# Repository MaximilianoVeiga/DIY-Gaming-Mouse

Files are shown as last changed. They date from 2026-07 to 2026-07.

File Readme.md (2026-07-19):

# DIY Gaming Mouse

Video about why and how I made this, and what the various iterations were like: https://www.youtube.com/watch?v=h-Cdl4Vq9H4

This repository contains the code, schematic, PCB layout, and 3d model for a completely DIY gaming mouse, all designed around a Pixart PMW3360 sensor.

The firmware for this mouse uses a special debouncing algorithm that completely eliminates chatter without adding ANY latency, and eliminates bounce better than commercial mice do. Random double-clicks be gone!

None of the companies that make gaming mouse sensors sell them to consumers, including Pixart, so the sensor needs to be salvaged (or bought from a scalper, or a small business that specializes in reselling them).

<table>
  <tr>
    <td>
      
    </td>
    <td>
      
    </td>
  </tr>
  <tr>
    <td>
      opened mouse
    </td>
    <td>
      assembled mouse
    </td>
  </tr>
</table>

(The shell has a top, too, but it's turned off in this picture so you can see the PCB.)

## Features

- True zero-latency button debouncing with no glitching
- Buttons that will not develop double-clicking problems after only a few months
- Low-latency motion tracking (no smoothing)
- Completely open source (Apache 2.0 license)
- Even the hardware is open source! (except the processor and sensor)
- Ultra light-weight shell and assembly (55g in total)
- Fingertip-grip shell shape
- Extra middle mouse button
- - the button that normally controls DPI on other mice is mapped to M3
- PCB exposes extra unused pins from the rp2040 as test pads for hardware/firmware modding fun; attach your own sensors! or LEDs! whatever you want!
- Full 1000hz tracking

### Runtime controls

- **DPI** (default 1200): hold LMB + RMB + DPI + M4 and scroll the wheel. Saved to flash ~2 seconds after the last change (mbed KVStore), so it survives reboot. Fallback default is `DPI_DEFAULT` in `3360_Mouse_pico.ino` (value is DPI/100).
- **Lift-off distance / LOD** (default 2 mm): hold LMB + RMB + DPI + M5 and scroll the wheel. Range is 2–3 mm; also persisted after the same ~2 s debounce.
- **Button remapping**: compile-time only. Edit the `BUTTON_MAP[]` table in `3360_Mouse_pico.ino`. By default M3 and the DPI button share middle-click (last press wins), M4 is back, M5 is forward.

### Sensor modes

- With a real `srom_3360_0x05.h`, the firmware uploads SROM and checks SROM ID + Observation (SROM running).
- Without a real SROM, the build still succeeds using `srom_dummy_blank.h` and runs in **degraded** mode (tracking enabled, but spinouts/teleports are possible).
- If SPI/product-ID checks fail repeatedly, the mouse enters **limp mode**: buttons and wheel keep working, motion is suppressed, and recovery is retried every few idle seconds.

### Building the firmware

Main mouse firmware uses **Arduino Mbed OS RP2040 Boards** (`arduino:mbed_rp2040`), not earlephilhower `arduino-pico`.

```bash
arduino-cli core update-index
arduino-cli core install arduino:mbed_rp2040@4.6.0
# Sketch folder name must match the .ino basename:
mkdir -p /tmp/3360_Mouse_pico
cp 3360_Mouse_pico.ino relmouse_16.h srom_dummy_blank.h /tmp/3360_Mouse_pico/
# optional: cp srom_3360_0x05.h /tmp/3360_Mouse_pico/
arduino-cli compile --fqbn arduino:mbed_rp2040:pico /tmp/3360_Mouse_pico
```

Or open `3360_Mouse_pico.ino` in Arduino IDE 2.x and select an **Arduino Mbed OS RP2040** Pico board. See [HARDWARE_VERIFY.md](HARDWARE_VERIFY.md) for post-flash checks.

The SROM capture tool under `bios/spi_recorder` requires the **arduino-pico** core instead:

```bash
arduino-cli config add board_manager.additional_urls https://github.com/earlephilhower/arduino-pico/releases/download/global/package_rp2040_index.json
arduino-cli core update-index
arduino-cli core install rp2040:rp2040
arduino-cli compile --fqbn rp2040:rp2040:rpipico bios/spi_recorder
```

CI compiles both sketches on every push (main firmware always uses the dummy SROM path; proprietary SROM headers stay gitignored).

### Lint / format

CI also runs `clang-format` and `cppcheck` on the firmware sources, and compiles with `--warnings all`.

Locally (requires `cppcheck` on `PATH`, and `clang-format` 22.x — e.g. `pip install clang-format==22.1.8`):

```bash
# Apply or check format (.ino treated as C++)
python3 scripts/clang_format_firmware.py
python3 scripts/clang_format_firmware.py --check

cppcheck --language=c++ --enable=warning,style,performance,portability --error-exitcode=1 \
  --suppress=missingIncludeSystem --suppress=unusedFunction \
  3360_Mouse_pico.ino relmouse_16.h bios/spi_recorder/spi_recorder.ino
```

SROM blob headers (`srom_dummy_blank.h`, `srom_3360_*.h`) are excluded from formatting.

### Hardware verification checklist

After flashing, confirm on a real mouse:

1. Boot serial shows product id `66` / inverse `189` (0x42 / 0xBD). With a real SROM, also check a non-zero SROM id and Observation with bit 6 set.
2. Change DPI with the DPI chord, wait ~2 seconds, unplug/replug: DPI should restore and print `settings: loaded ...`.
3. Change LOD with the LOD chord the same way; lift height tracking stop should change between 2 mm and 3 mm.
4. Buttons/wheel still work if the sensor is disconnected (limp mode); motion should stop without stuck clicks.
5. Fast motion + rapid clicks should not drop presses; USB fail/recover messages may appear only under host stress.

TODO:

- Runtime remapping / macros (compile-time map already exists)
- "fun" optional features like WMO-style diagonal jaggy removal or optional in-firmware acceleration, anti-smoothing (prediction), angle snapping, cinematic smoothing, etc

## Required skills

You need to be familiar with, or be able to learn quickly:

- 3d printing
- how to use a "slicer" (e.g. Cura) to convert stl models to gcode (what your 3d printer uses)
- repeatedly making test prints
- how to clean up 3d prints and remove support material from fragile prints
- basic firmware code debugging skills
- the ability to read embedded C/C++ code
- the Arduino IDE (I use 2.x, not 1.x)
- desoldering (with a hot air rework station)
- soldering (with a soldering iron)
- soldering bodge wires to existing pieces of hardware without creating solder bridges (for SROM extraction)
- comfort using a hot air rework station to soften and fix misshapen parts on 3d printed objects if they print improperly
- the ability to do all of the above without wasting tons of money or burning your home down
- familiarity with PCB printing companies and PCB assembly manufacturers (JLCPCB, PCBWay, etc)
- patience

If you cannot do all of the above, you should have someone else build this project for you, rather than building it for yourself. Or, at the very least, I can't give you support if you don't have the skills needed to make this; I'm just some random guy.

You also need:

- access to a 3d printer that you can repeatedly print test prints on until they come out right
- a hot air rework station with temperature and air flow rate control
- a soldering iron with temperature control
- hot glue device (for securing the USB cable, nothing else)
- various small tools like screwdrivers, tweezers, cleanup blades / deburring tools, etc. for various parts of the building process

## Instructions

### 3D printing the shell

This assumes you're using a filament printer. Resin printers might work too, but I have never used one.

I print with PLA filament.

Print each of the STL files in the "Case Model" directory in their natural (not default!) orientations. To repeat, some of the models have to be rotated; they're saved in the orientation they have in the mouse, not the orientation they need to have on the 3d printer's build plate.

You need to convert the stl files to gcode yourself and run various test prints because each 3d printer and filament has different requirements for layer thickness, support cutoff angle, printing speed, z seam alignment placement, etc.

Cura will complain about certain pieces (like the shell bottom) not being "water tight", but it's wrong; the watertightness check doesn't handle multiple overlapping solids properly. The models will still slice correctly and without glitches.

The thumb pieces must be rotated into the orientation where they do not need any supports. This means the small part of the thumb piece is facing up, and the long part of the switch clamp section is on the bottom.

The scroll wheel must be rotated so that the thick cylinder part is on the bottom and the thin pin part is on the top. It must be printed with supports; any type of support is fine. It should be printed at 100% speed or lower, not higher, until it gets to the pin, at which point you MUST reduce the printing speed as low as you can tolerate. On my printer, a Sovol SV06, I had to turn it down to 25% speed. If your printer doesn't allow you to change the speed mid-print, you have to print at the low speed for the entire print. This is important; you have to print it slowly, because otherwise, the pin will be misaligned with itself and the scroll wheel will be off-balance and hit the middle mouse button switch with different pressures depending on where it is in its spin cycle.

Print the scroll wheel brace as-is.

Print the shell bottom as-is. However, if you have a heated printbed or chamber, you need to wait for it to completely cool before removing it. If you remove the print while it's warm, the bottom will bend and the mouse won't sit flat. Even with mouse feet, the sensor will be at the wrong height if the bottom is bent.

Print the shell top with tree supports and a support cutoff angle between 60 and 70 degrees. Do not use "standard"/traditional/grid supports; they will be too difficult to remove, and you will probably damage the print trying to remove them. On my printer, a Sovol SV06, 67 degrees was just right. If you have poor print quality, you might need to reduce the cutoff angle down to something silly like 50 degrees. If you have to go below 50 degrees, get a better printer, or make sure you're using the right filament at the right temperature, etc.

Once the shell top is printed, you need to use a deburring tool (or other hard, sharp metal implement) to remove a small amount of material from a certain curved edge along the seam where it meets the shell bottom, on the right side of the shell (with the button pieces away from you and the "butt" part towards you). The shell will fit together without removing a small amount of material from this part of the shell top, but it'll be misaligned by around a quarter of a millimeter and the right click won't quite work right. This material has to be removed because it sags during printing, and it sags during printing because of how support bridging works; the 3d model itself is correct.

You should print each part one-by-one and check for errors each time.

The final result will be somewhat rough and rugged, but it's a functional mouse shell.

### SROM preparation

Note: The SROM is optional, but highly recommended because it contains sensor firmware bugfixes. The firmware builds without an SROM: if `srom_3360_0x05.h` is missing, it falls back to `srom_dummy_blank.h` and skips SROM upload (with a serial warning). Without a real SROM, your mouse might experience glitchy behavior like "spinout" or have generally poor tracking. For example, while writing this and testing the firmware without an SROM, I click-and-dragged a title bar on a window, and then the mouse cursor teleported 300~400 pixels to the right for no reason.

The SROM needs to be captured from an existing mouse because it's copyrighted. Give it the name `srom_3360_0x03.h`, `srom_3360_0x04.h`, or `srom_3360_0x05.h`, depending on what version it is. I poked around github and found other projects using the 3360 SROM, and this seems to be the way they decided to name their SROM header files, so I'm copying the filename from them.

Once you have the SROM, place `srom_3360_0x05.h` next to `3360_Mouse_pico.ino` (or adjust the `__has_include` path in that file for your version). The sketch will pick it up automatically.

The below is instructions on how to capture the SROM from a commercial mouse.

Capture the SROM from a commercial 3360 mouse with this code, and a standalone raspberry pi pico (not this mouse's custom PCB): https://gist.github.com/wareya/0dc3498bd80be93c47b6f79aa9164321

Note: the above SROM capturing code requires you to use the "arduino-pico" board type in the Arduino IDE. But the firmware in this repostory requires you to use the "mbed OS" rp2040 board type.

Use a breadboard to make a ripping setup equivalent to that depicted in the following image:

EspAlvz

And this post: https://github.com/wareya/DIY-Gaming-Mouse/issues/6#issuecomment-2340009477

Be very careful not to create any solder bridges between any of the pins on the 3360.

Reconnect the mouse so that it reboots and sends the SROM to the sensor again.

The output should be exactly 4094 bytes long, and the second byte should be 0x03, 0x04, or 0x05 (different versions).

Repeat the capturing process until you get the same SROM several times, just to make sure that it captured properly. To capture the SROM again, you need to reboot the mouse. This can be plugging it in to your computer again, or disconnecting and reconnecting its USB power wire, or any safe method you prefer.

The MD5 checksums of the versions of the SROM that I know about are:

```
0x03 - C64F2BDA742DD1623D6A5DC869FC5E60
0x04 - 0BCB410858FF21D091DDC497D19BC943
0x05 - 337254C54AD82C689D4B9A58D06A3CF6
```

If you have an SROM with a different version number, it might not work with this firmware. It might, but it also might not. I can't provide support for other SROM versions.

After capturing the SROM data, save it in a formatted .h file formatted as such:

```c

#define SROM_LENGTH (4094)

const uint8_t PROGMEM srom[SROM_LENGTH] =
{
0x01,
0x<version number>,
// ...
// etc
};
```

I cannot distribute the SROM in this repository, because it's copyrighted proprietary code.

Disclaimer: The above steps do not bypass any copy protection, no encryption is being broken, and copyright law is not being violated by making your own backup copy of the sensor's SROM and using it on your own device. This is fully legal in reasonable countries (like the US).

### PMW 3360 sensor salvage

The Pixart PMW3360 is not sold commercially to hobbyists or small repair shops; to get one, you have to either buy an expensive breakout board, buy it from scalpers on aliexpress (or similar), or salvage it from an existing commercial mouse. This project assumes that you're salvaging it from an existing commercial mouse, after capturing the SROM from that mouse.

You need a hot air rework station, NOT a soldering iron, to desolder and salvage the 3360 safely. If you try to use a soldering iron, even with desoldering wick and/or a desoldering pump, you are VERY likely to fail to salvage it, damaging the pins or sensor internals in the process. The 3360 is somewhat sensitive to high temperatures, so you can only heat it up for a fairly short amount of time, and desoldering the ground pin with a soldering iron will get the sensor hot enough that it might start to damage it.

The 3360 sensor's lens is usually directly mounted to the sensor by melting its clear mounting pins down onto the top of the sensor's IC package.

Take the commercial mouse's PCB, scrape off (don't break off) the top melted part of the lens's mounting posts. Then, being careful not to damage anything, remove the lens from the sensor and PCB and put it somewhere safe.

Now, put the commercial mouse's PCB upside down on a non-flammable surface, in a workspace free of any flammable material. I cannot be held responsible if you start a fire in an unsafe workspace. You have been warned!

Before continuing, you might want to cover the bottom of the sensor with paper and/or tape to prevent anything from getting inside of it. If you do this, do it in a way that doesn't create a fire hazard.

Find the bottom of the sensor's pins. To each of these pins, apply a small amount of either leaded solder (if it's all you have) or low-temperature non-leaded solder paste/gel/etc (preferred) (NOT the same thing as flux!). You want to mix your solder into the existing solder on the pins because this will lower the melting temperature of the existing solder and make it easier to desolder the chip. Use a soldering iron or hot air tool at around 600F/300C to make the two types of solder mix together. Do not physically touch the PCB or pins with the hot air tool; rely only on the air itself.

Once the solder for each pin is mixed together, pass the hot air tool over each section of pins in a circular motion until the sensor eventually, finally comes loose. At this point, use any metal tool (like metal tweezers or a screw driver) to make sure the sensor fully comes out of the PCB.

Now, use a soldering iron to clean any excess remaining solder off of the pins. If the soldering iron ends up with too much solder on it, clean it off with brass/bronze wool or similar. Be warned that, at very high temperatures, brass wool is flammable. Do not use steel wool as a subtitute, as it is even more flammable.

### PCB building and assembly

Build gerber files and drill files and all the other necessary files (BOM, pick and place, etc) that your PCB manufacturer needs to print **and assemble** the PCB. Some of the components on the PCB are very, very delicate, so unless you're a genuine expert, trying to hand-solder them is doomed.

The plugin I use to manage JLCPCB part mappings is https://github.com/Bouni/kicad-jlcpcb-tools - this is the plugin that uses the `project.db` file. However, this file is just an sqlite database, so if you want to make sure you use the right parts with another manufacturer, you can open it up with any sqlite database viewer and get the LCSC part numbers and look them up individually, then find the equivalent part for your PCBA manufacturer. However, the PCB isn't designed to require you to do this; you can look up the parts individually instead (based on their values).

Once you have your PCBs, you need the following parts to manually solder to the board:

- 6 Omron D2F-01F switches (or compatible, e.g. D2FC)
- 11mm Alps-compatible scroll wheel encoder
- salvaged PMW 3360 sensor, undamaged, pins not bent
- - 3360 sensor's lens, with mounting posts still intact
- Four dupont-compatible header pins for connecting to USB cable (optional)
- spare discrete resistors in case you messed up any of the resistor values when ordering the PCB like I did

And the following additional parts for assembly:

- USB cable, ideally with dupont-compatible connectors (you can crimp them on yourself, you don't have to buy a special cable for this)
- 3d printed shell (2 parts)
- 3d printed side buttons (2 parts)
- 3d printed scroll wheel brace (1 part)
- 3d printed scroll wheel OR salvaged scroll wheel for 11mm Alps-compatible scroll wheel encoder with the right middle-mouse-button shaft thickness
- mouse feet (salvaged or custom) with approximately 0.6mm thickness (that's zero-point-six millimeters)

The mouse feet thickness is very important, within a quarter of a millimeter! Using any other thickness of mouse feet is likely to result in poor, glitchy tracking. The PMW3360 is VERY sensitive to VERY small changes in tracking distance.

Make sure you have screws the right size to screw everything together. I recommend doing a test-fit of the shell and plain PCB with screws before doing anything else. Be careful not to overtighten the side screws; doing so can cause their mounting holes to split. The PCB is held down with two screws and the case is held together with three screws. I used salvaged screws with a major diameter (outside edge of threads) of 2mm and a minor diameter of around 1.65~1.7mm, and the holes on the case were designed around these screws, but slightly different screws will still work.

PPRKHyR

Solder the dupont-compatible header pins to the PCB, or if you have a different plan to connect the PCB to USB, do that instead. Then, connect it to your computer and make sure you can program it with the Arduino IDE. If it doesn't work, try a different copy of the PCB. Don't continue until you know that the PCB and its rp2040 processor are working properly. You should also do a test-fit of the PCB inside the 3d printed shell bottom to make sure nothing went wrong in 3d printing, and that the edge cuts and drill holes on the PCB are accurate to how they were specified in the design files.

Solder each Omron switch to the board with the plungers aligned with the outline on the silkscreen illustration. Check and double check that the switches are fully flush with the board before and while you solder them; double check that they're flush after soldering the first pin.

Test fit the PCB into the shell bottom, and without screwing anything into anything else, attach the top half of the shell and make sure that the buttons can be clicked properly and aren't clicked just by attaching the top half of the shell. If they're hard to click or they click themselves, your 3d printer has poor tolerances, and you may need to adjust the button pieces by softening them with the hot air tool and bending them slightly until they fit just right. Once you're done here, remove the PCB from the shell.

Solder the scroll wheel encoder in into the RotaryEncoder footprint on the PCB. Be very sure that it's all the way down before and while soldering it. You may need to twist the pins very slightly with a pair of needle-nose pliers to get them to fit into their holes; the holes are very narrow, on purpose, to reduce the chance of solder bridges forming between them.

firefox_2024-04-07_00-51-23

(Example photo of a 11mm Alps-compatible encoder. 11mm is the distance between the center of the rotor and the surface of the PCB, not the top to bottom of the entire encoder.)

Solder the PMW3360 sensor to the center of the PCB, making VERY, VERY sure that it's in ALL THE WAY before and while soldering it. If it's not in all the way, the PCB may not fit properly in the shell, and/or the sensor may fail to track properly. The sensor must be mounted "upside-down" relative to the rest of the board, such that the text on it is upside-down compared to the text at the top of the board. If you put the sensor in the wrong way, it will look uncentered; if you put it in the right way (upside-down), it will look centered. If you get the wrong, the sensor might fry itself when you turn the mouse on, and the lens might not even fit against the sensor through the PCB.

Attach the lens to the sensor on the underside of the PCB. Then, slot the PCB into the bottom shell and make sure it fully fits all the way down.

If, at this point, you connect the mouse to USB again and check what it says in the Arduino IDE's "Serial Logger" when the mouse boots, and the SROM's ID is a value other than zero or 0xFF, the sensor is working properly. If it's working properly but still doesn't track, double check the value of the LED resistor; that's the component closest to the "U10" silkscreen text, also near four diodes arranged in a rectangle (not in a row). The resistor value should be 39 ohms, or something very close like 40. If the resistor value is wrong, you have to desolder it and bodge on 40 ohms worth of discrete resistors (I personally use two 20 ohm resistors in series). WARNING: Using too few ohms will permanently damage the sensor's LED and make the sensor useless.

Remove the PCB and fit the side button thumb pieces to their switches. This is difficult and should feel like you're almost going to break the thumb pieces, but not like you're definitely going to break them. The long piece of the switch brace should wrap around the "inside" of the switches (towards the other side button switch), not the "outside". To get the thumb pieces around the switches, first fit the "hook" to the bottom around the edge of the PCB, slightly offset from the switch, and rotate the thumb piece down so that the far end of its brace hits the top of the switch. Move it as far from the switch as you comfortably can, so that it doesn't have to bend too much to slide down past the top and around the other side of the switch. Once that happens, slide it towards the switch so that the small hook piece at the end of the brace fully wraps around the other corner of the switch. Repeat this for the other switch's thumb piece.

firefox_2024-04-08_01-20-12 firefox_2024-04-08_01-20-14 firefox_2024-04-08_01-20-17 firefox_2024-04-08_01-20-19

Above is a visual image series depicting the process for mounting the thumb button pieces. It's OK if they crack or break while attempting to fit them; they will still fit and work, just be slightly less snug than they're supposed to be.

Fit scroll wheel brace around the middle mouse button (near the right mouse button), with the spikes towards the "inside" of the mouse and away from the middle mouse button. Now fit the scroll wheel and make sure it's snug and properly balanced. If it's not, you'll need to reprint it.

Put the PCB back into the shell bottom and make sure it's still snug. Route the USB cable behind the support post in the back of the case (it has a screw hole in it) and around the right side of the PCB (NOT the left side), hugging the right side of the right mouse button, and then feed it out through the slot in the front. Use hot glue to secure the USB cable to that front slot. Make sure that it points relatively straight out the front when you hot glue it down.

Plug it in, compile and upload the firmware from the Arduino IDE, and make sure everything works. If it does, you're done! Just re-screw everything together. Be careful not to overtighten the side screws; doing so can cause their mounting holes to split.

## License

3360_Mouse_pico.ino, the main file of this project, is released under the Apache License, version 2.0.

relmouse_16.h is based on files from mbed OS, also licensed under the Apache License, version 2.0. https://github.com/arduino/ArduinoCore-mbed

The hardware design files (under "Case Model" and "KiCad schematic + PCB") are licensed under the SolderpadLicense, version 2.1, as follows:

```
Copyright 2024 wareya
SPDX-License-Identifier: Apache-2.0 WITH SHL-2.1

Licensed under the Solderpad Hardware License v 2.1 (the “License”); you may not use this file except in compliance with the License, or, at your option, the Apache License version 2.0. You may obtain a copy of the License at

https://solderpad.org/licenses/SHL-2.1/

Unless required by applicable law or agreed to in writing, any work distributed under the License is distributed on an “AS IS” BASIS, WITHOUT WARRANTIES OR CONDITIONS OF ANY KIND, either express or implied. See the License for the specific language governing permissions and limitations under the License.
```

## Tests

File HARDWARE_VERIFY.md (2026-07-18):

# Hardware verification

Use this checklist after flashing improved firmware. CI only proves compilation with the dummy SROM path.

## Boot / sensor

- [ ] Serial shows `product id: 66 (inverse: 189)` (0x42 / 0xBD)
- [ ] With real SROM: non-zero `srom id` and `observation` with bit 6 set (`ok`)
- [ ] Without real SROM: degraded-mode warning, buttons/wheel/motion still function

## Settings persistence

- [ ] DPI chord (LMB+RMB+DPI+M4 + wheel) changes DPI; after ~2 s serial prints `settings: saved`
- [ ] Power cycle restores DPI (`settings: loaded`)
- [ ] LOD chord (LMB+RMB+DPI+M5 + wheel) changes 2–3 mm and persists the same way
- [ ] Corrupt/missing KV record falls back to 1200 DPI / 2 mm LOD

## USB / input

- [ ] Rapid motion + clicks do not leave buttons stuck
- [ ] Under host stress, occasional `usb: recovered` is acceptable; cursor should not jump wildly after recover
- [ ] Wheel does not skip at moderate scroll speeds (~1 kHz report path)

## Limp / recovery

- [ ] Disconnecting sensor SPI (or bad wiring) enters limp mode: motion stops, buttons/wheel still work
- [ ] After reconnect and a few idle seconds, recovery attempt restores motion when IDs validate

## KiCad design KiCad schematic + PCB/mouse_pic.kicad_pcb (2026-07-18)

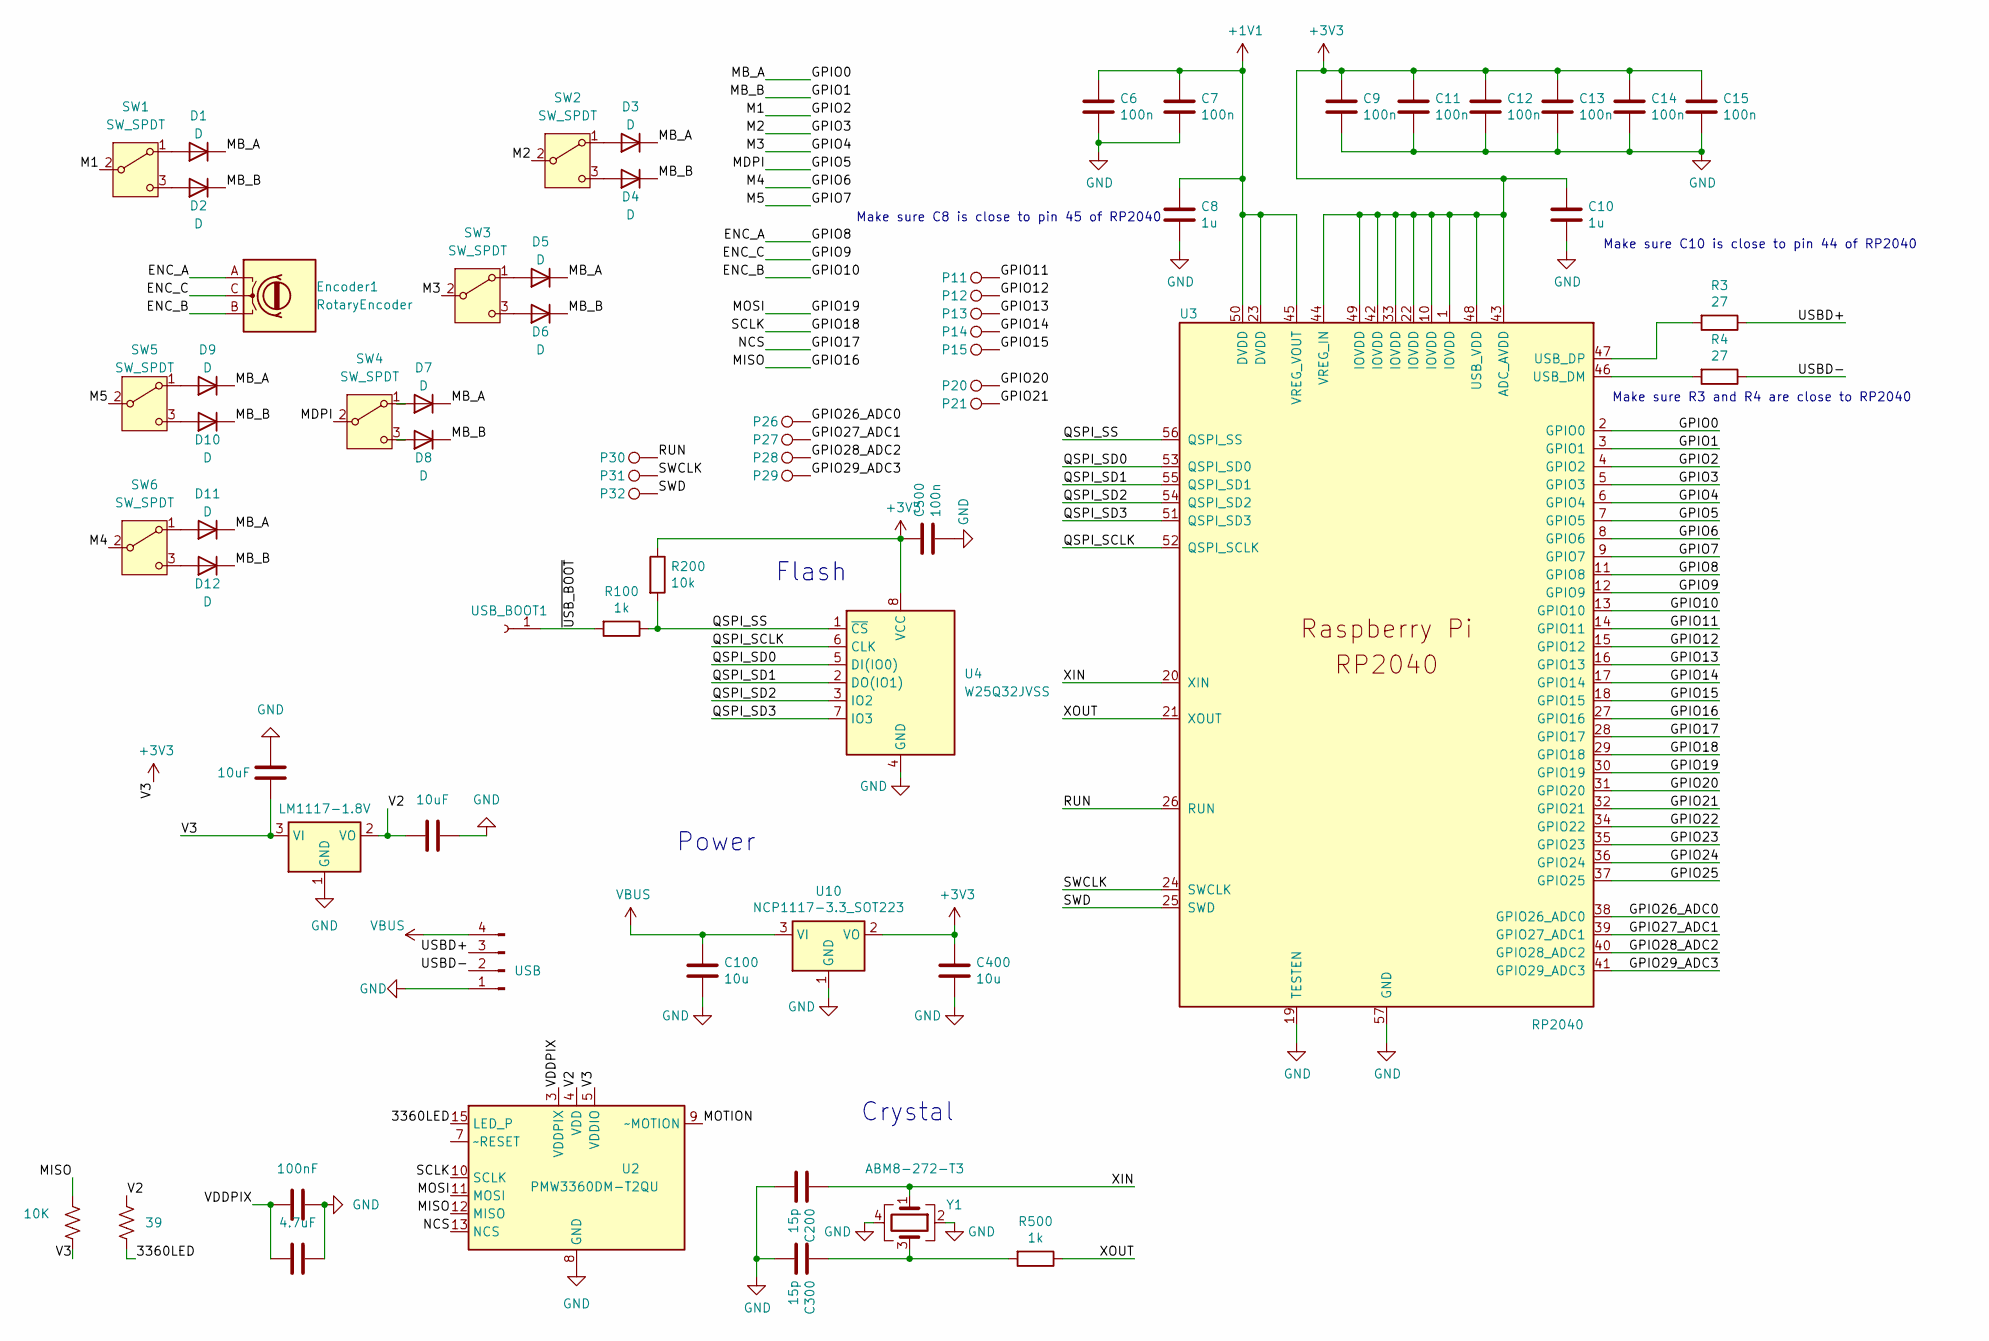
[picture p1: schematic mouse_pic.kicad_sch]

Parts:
C1, C2: 10uF; C_0603_1608Metric
C3: 100nF; C_0603_1608Metric
C4: 4.7uF; C_0603_1608Metric
C6, C7, C9, C11, C12, C13, C14, C15, C500: 100n; C_0603_1608Metric
C8, C10: 1u; C_0603_1608Metric
C100, C400: 10u; C_0603_1608Metric
C200, C300: 15p; C_0603_1608Metric
D1, D2, D3, D4, D5, D6, D7, D8, D9, D10, D11, D12: D; D_SOD-123
Encoder1: RotaryEncoder; Alps-EC10E1220501
P11, P12, P13, P14, P15, P20, P21, P26, P27, P28, P29, P30, P31, P32: TestPoint; TestPoint_Pad_D1.0mm
R1: 10K; R_0603_1608Metric
R3, R4: 27; R_0603_1608Metric
R40: 39; R_0603_1608Metric
R100, R500: 1k; R_0603_1608Metric
R200: 10k; R_0603_1608Metric
SW1, SW2, SW3, SW4, SW5, SW6: SW_SPDT; SW_Tactile_SPDT_Omron_D2F
U1: LM1117-1.8V; SOT-223-3_TabPin2
U2: PMW3360DM-T2QU; PixArt_PDIP-16_10.9x16.2mm_P1.78mm
U3: RP2040; RP2040-QFN-56
U4: W25Q32JVSS; SOIC-8_5.275x5.275mm_P1.27mm
U10: NCP1117-3.3_SOT223; SOT-223-3_TabPin2
USB1: USB; PinHeader_1x04_P2.54mm_Vertical
USB_BOOT1: Conn_01x01_Socket; TestPoint_THTPad_D2.0mm_Drill1.0mm_Edit
Y1: ABM8-272-T3; Crystal_SMD_3225-4Pin_3.2x2.5mm

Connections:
+1V1: C6.1, C7.1, C8.1, U3.23 (DVDD), U3.45 (VREG_VOUT), U3.50 (DVDD)
+3V3: C1.1, C9.1, C10.1, C11.1, C12.1, C13.1, C14.1, C15.1, C400.1, C500.1, R1.2, R200.1, U1.3 (VI), U2.5 (VDDIO), U3.1 (IOVDD), U3.10 (IOVDD), U3.22 (IOVDD), U3.33 (IOVDD), U3.42 (IOVDD), U3.43 (ADC_AVDD), U3.44 (VREG_IN), U3.48 (USB_VDD), U3.49 (IOVDD), U4.8 (VCC), U10.2 (VO)
/3360LED: R40.1, U2.15 (LED_P)
/ENC_A: Encoder1.A, U3.11 (GPIO8)
/ENC_B: Encoder1.B, U3.13 (GPIO10)
/ENC_C: Encoder1.C, U3.12 (GPIO9)
/GPIO0: D1.1 (K), D3.1 (K), D5.1 (K), D7.1 (K), D9.1 (K), D11.1 (K), U3.2 (GPIO0)
/GPIO1: D2.1 (K), D4.1 (K), D6.1 (K), D8.1 (K), D10.1 (K), D12.1 (K), U3.3 (GPIO1)
/GPIO2: SW1.2 (B), U3.4 (GPIO2)
/GPIO3: SW2.2 (B), U3.5 (GPIO3)
/GPIO4: SW3.2 (B), U3.6 (GPIO4)
/GPIO5: SW4.2 (B), U3.7 (GPIO5)
/GPIO6: SW6.2 (B), U3.8 (GPIO6)
/GPIO7: SW5.2 (B), U3.9 (GPIO7)
/GPIO11: P11.1, U3.14 (GPIO11)
/GPIO12: P12.1, U3.15 (GPIO12)
/GPIO13: P13.1, U3.16 (GPIO13)
/GPIO14: P14.1, U3.17 (GPIO14)
/GPIO15: P15.1, U3.18 (GPIO15)
/GPIO16: R1.1, U2.12 (MISO), U3.27 (GPIO16)
/GPIO17: U2.13 (NCS), U3.28 (GPIO17)
/GPIO18: U2.10 (SCLK), U3.29 (GPIO18)
/GPIO19: U2.11 (MOSI), U3.30 (GPIO19)
/GPIO20: P20.1, U3.31 (GPIO20)
/GPIO21: P21.1, U3.32 (GPIO21)
/GPIO22: U3.34 (GPIO22)
/GPIO23: U3.35 (GPIO23)
/GPIO24: U3.36 (GPIO24)
/GPIO25: U3.37 (GPIO25)
/GPIO26_ADC0: P26.1, U3.38 (GPIO26_ADC0)
/GPIO27_ADC1: P27.1, U3.39 (GPIO27_ADC1)
/GPIO28_ADC2: P28.1, U3.40 (GPIO28_ADC2)
/GPIO29_ADC3: P29.1, U3.41 (GPIO29_ADC3)
/MOTION: U2.9 (~MOTION)
/QSPI_SCLK: U3.52 (QSPI_SCLK), U4.6 (CLK)
/QSPI_SD0: U3.53 (QSPI_SD0), U4.5 (DI(IO0))
/QSPI_SD1: U3.55 (QSPI_SD1), U4.2 (DO(IO1))
/QSPI_SD2: U3.54 (QSPI_SD2), U4.3 (IO2)
/QSPI_SD3: U3.51 (QSPI_SD3), U4.7 (IO3)
/QSPI_SS: R100.1, R200.2, U3.56 (QSPI_SS), U4.1 (~CS)
/RUN: P30.1, U3.26 (RUN)
/SWCLK: P31.1, U3.24 (SWCLK)
/SWD: P32.1, U3.25 (SWD)
/USBD+: R3.1, USB1.3
/USBD-: R4.1, USB1.2
/V2: C2.1, R40.2, U1.2 (VO), U2.4 (VDD)
/VDDPIX: C3.1, C4.1, U2.3 (VDDPIX)
/XIN: C200.1, U3.20 (XIN), Y1.1
/XOUT: R500.1, U3.21 (XOUT)
/~USB_BOOT: R100.2, USB_BOOT1.1
GND: C1.2, C2.2, C3.2, C4.2, C6.2, C7.2, C8.2, C9.2, C10.2, C11.2, C12.2, C13.2, C14.2, C15.2, C100.2, C200.2, C300.2, C400.2, C500.2, U1.1 (GND), U2.8 (GND), U3.19 (TESTEN), U3.57 (GND), U4.4 (GND), U10.1 (GND), USB1.1, Y1.2, Y1.4
unnamed: C300.1, R500.2, Y1.3
unnamed: D1.2 (A), SW1.1 (A)
unnamed: D2.2 (A), SW1.3 (C)
unnamed: D3.2 (A), SW2.1 (A)
unnamed: D4.2 (A), SW2.3 (C)
unnamed: D5.2 (A), SW3.1 (A)
unnamed: D6.2 (A), SW3.3 (C)
unnamed: D7.2 (A), SW4.1 (A)
unnamed: D8.2 (A), SW4.3 (C)
unnamed: D9.2 (A), SW5.1 (A)
unnamed: D10.2 (A), SW5.3 (C)
unnamed: D11.2 (A), SW6.1 (A)
unnamed: D12.2 (A), SW6.3 (C)
unnamed: R4.2, U3.46 (USB_DM)
unnamed: R3.2, U3.47 (USB_DP)
VBUS: C100.1, U10.3 (VI), USB1.4

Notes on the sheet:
Power
Crystal
Make sure C8 is close to pin 45 of RP2040
Make sure C10 is close to pin 44 of RP2040
Make sure R3 and R4 are close to RP2040
Flash

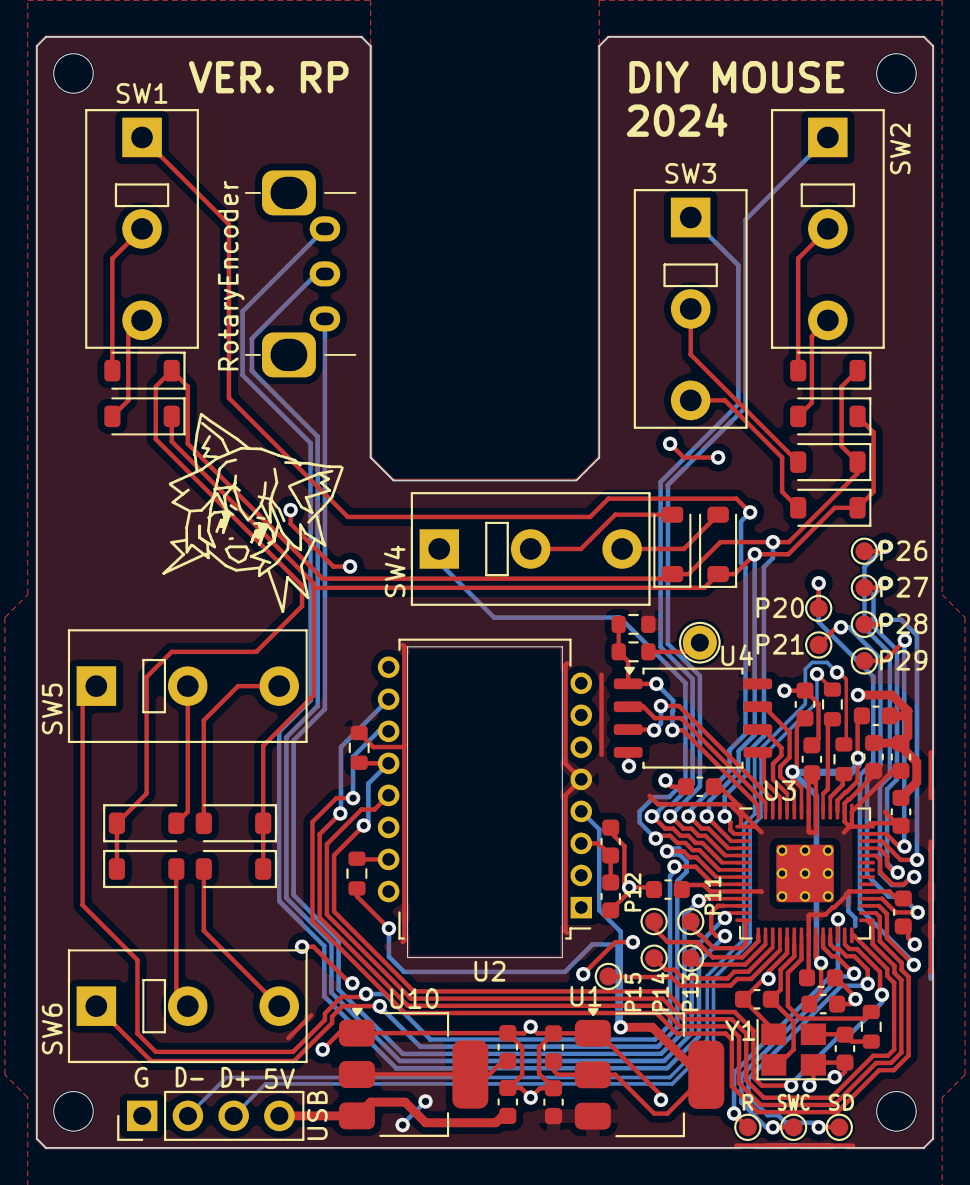
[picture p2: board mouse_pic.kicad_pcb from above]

Board: 2 copper layers, 49.8 x 61.7 mm, 67 parts (0 on the bottom side), 62 nets.

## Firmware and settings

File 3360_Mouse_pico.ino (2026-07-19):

/*
 * Copyright (c) 2024, wareya
 * SPDX-License-Identifier: Apache-2.0
 *
 * Licensed under the Apache License, Version 2.0 (the "License");
 * you may not use this file except in compliance with the License.
 * You may obtain a copy of the License at
 *
 *     http://www.apache.org/licenses/LICENSE-2.0
 *
 * Unless required by applicable law or agreed to in writing, software
 * distributed under the License is distributed on an "AS IS" BASIS,
 * WITHOUT WARRANTIES OR CONDITIONS OF ANY KIND, either express or implied.
 * See the License for the specific language governing permissions and
 * limitations under the License.
 */

#include <SPI.h>
#include <mbed.h>
#include <kvstore_global_api.h>

REDIRECT_STDOUT_TO(Serial);

#include <PluggableUSBHID.h>

#if __has_include("srom_3360_0x05.h")
#include "srom_3360_0x05.h"
#define HAVE_REAL_SROM 1
#else
#include "srom_dummy_blank.h"
#endif
#include "relmouse_16.h"
USBMouse16 mouse(false);

#define REG_PRODUCT_ID (0x00)
#define REG_REVISION_ID (0x01)
#define REG_MOTION (0x02)
#define REG_DELTA_X_L (0x03)
#define REG_DELTA_X_H (0x04)
#define REG_DELTA_Y_L (0x05)
#define REG_DELTA_Y_H (0x06)
#define REG_SQUAL (0x07)
#define REG_RAW_DATA_SUM (0x08)
#define REG_MAX_RAW_DATA (0x09)
#define REG_MIN_RAW_DATA (0x0A)
#define REG_SHUTTER_LOWER (0x0B)
#define REG_SHUTTER_UPPER (0x0C)
#define REG_CONTROL (0x0D)

#define REG_CONFIG1 (0x0F)
#define REG_CONFIG2 (0x10)
#define REG_ANGLE_TUNE (0x11)
#define REG_FRAME_CAPTURE (0x12)
#define REG_SROM_ENABLE (0x13)
#define REG_RUN_DOWNSHIFT (0x14)
#define REG_REST1_RATE_LOWER (0x15)
#define REG_REST1_RATE_UPPER (0x16)
#define REG_REST1_DOWNSHIFT (0x17)
#define REG_REST2_RATE_LOWER (0x18)
#define REG_REST2_RATE_UPPER (0x19)
#define REG_REST2_DOWNSHIFT (0x1A)
#define REG_REST3_RATE_LOWER (0x1B)
#define REG_REST3_RATE_UPPER (0x1C)

#define REG_OBSERVATION (0x24)
#define REG_DATA_OUT_LOWER (0x25)
#define REG_DATA_OUT_UPPER (0x26)

#define REG_RAW_DATA_DUMP (0x29)
#define REG_SROM_ID (0x2A)
#define REG_MIN_SQ_RUN (0x2B)
#define REG_RAW_DATA_THRESHOLD (0x2C)

#define REG_CONFIG5 (0x2F)

#define REG_POWER_UP_RESET (0x3A)
#define REG_SHUTDOWN (0x3B)

#define REG_INVERSE_PRODUCT_ID (0x3F)

#define REG_LIFTCUTOFF_TUNE3 (0x41)
#define REG_ANGLE_SNAP (0x42)

#define REG_LIFTCUTOFF_TUNE1 (0x4A)

#define REG_MOTION_BURST (0x50)

#define REG_LIFTCUTOFF_TUNE_TIMEOUT (0x58)

#define REG_LIFTCUTOFF_TUNE_MIN_LENGTH (0x5A)

#define REG_SROM_LOAD_BURST (0x62)
#define REG_LIFT_CONFIG (0x63)
#define REG_RAW_DATA_BURST (0x64)
#define REG_LIFTOFF_TUNE2 (0x65)

#define CONFIG2_REST_ENABLED (0x30)
#define CONFIG2_REPORT_MODE (0x04)

// PMW3360 identity / Observation
#define PMW3360_PRODUCT_ID 0x42
#define PMW3360_INVERSE_PRODUCT_ID 0xBD
#define OBS_SROM_RUNNING (1u << 6)

// Pins
#define BUTTONS_ON 0
#define BUTTONS_OFF 1
#define BUTTON_M1 2
#define BUTTON_M2 3
#define BUTTON_M3 4
#define BUTTON_DPI 5
#define BUTTON_M4 6
#define BUTTON_M5 7
#define ENCODER_A 8
#define ENCODER_B 10
#define ENCODER_COM 9
#define PIN_NCS 17
#define PIN_MISO 16
#define PIN_MOSI 19
#define PIN_SCK 18

// Physical button bit indexes in `buttons`
enum PhysButton : uint8_t {
    PHYS_M1 = 0,
    PHYS_M2 = 1,
    PHYS_M3 = 2,
    PHYS_DPI = 3,
    PHYS_M4 = 4,
    PHYS_M5 = 5,
    PHYS_COUNT = 6
};

#define PHYS_BIT(i) (1u << (i))

// HID report button bits (5-button report in relmouse_16.h)
enum HidButton : uint8_t {
    HID_LEFT = 0,
    HID_RIGHT = 1,
    HID_MIDDLE = 2,
    HID_BACK = 3,
    HID_FORWARD = 4,
    HID_NONE = 0xFF,
    // M3 and DPI share middle-click; either pressed asserts middle
    HID_MIDDLE_SHARED = 0xFE
};

// Compile-time physical -> HID map. Edit here to rebind buttons.
// Default matches stock firmware: M3/DPI share middle, M4=back, M5=forward.
static const uint8_t BUTTON_MAP[PHYS_COUNT] = {
    HID_LEFT,          // PHYS_M1
    HID_RIGHT,         // PHYS_M2
    HID_MIDDLE_SHARED, // PHYS_M3
    HID_MIDDLE_SHARED, // PHYS_DPI
    HID_BACK,          // PHYS_M4
    HID_FORWARD        // PHYS_M5
};

// Timing (us unless noted)
#define T_NCS_SCLK_US 1
#define T_SRAD_US 160
#define T_SCLK_NCS_WRITE_US 35
#define T_SRAD_MOTBR_US 35
#define T_SWW_SWR_US 180
#define T_SRW_SRR_US 20
#define T_BEXIT_US 1
#define T_SROM_BYTE_US 15
#define WHEEL_POLL_US 250
#define BUTTON_LATCH_LOOPS 8
#define BOOT_SERIAL_DELAY_MS 500
#define SETTINGS_FLUSH_MS 2000
#define SENSOR_FAIL_STREAK_LIMIT 8
#define SENSOR_RECOVERY_COOLDOWN_MS 5000

// DPI / LOD
#define DPI_DEFAULT 12 // hundreds: 1200
#define DPI_MIN 1
#define DPI_MAX 120
#define LOD_DEFAULT 2
#define LOD_MIN 2
#define LOD_MAX 3

#define CHORD_DPI (PHYS_BIT(PHYS_M1) | PHYS_BIT(PHYS_M2) | PHYS_BIT(PHYS_DPI) | PHYS_BIT(PHYS_M4))
#define CHORD_LOD (PHYS_BIT(PHYS_M1) | PHYS_BIT(PHYS_M2) | PHYS_BIT(PHYS_DPI) | PHYS_BIT(PHYS_M5))

#define SETTINGS_KEY "/kv/diymouse_cfg"
#define SETTINGS_MAGIC 0x44594D53u /* 'DYMS' */
#define SETTINGS_VERSION 1

static SPISettings spisettings(2000000, MSBFIRST, SPI_MODE3);

struct MotionBurstData {
    uint8_t motion;
    uint8_t observation;
    int16_t x;
    int16_t y;
    uint8_t squal;
};

struct SettingsRecord {
    uint32_t magic;
    uint16_t version;
    uint8_t dpi;
    uint8_t lod;
    uint32_t crc;
};

static uint32_t crc32_update(uint32_t crc, const uint8_t *data, size_t len) {
    crc = ~crc;
    for (size_t i = 0; i < len; i++) {
        crc ^= data[i];
        for (int b = 0; b < 8; b++)
            crc = (crc >> 1) ^ (0xEDB88320u & (uint32_t)-(int32_t)(crc & 1u));
    }
    return ~crc;
}

// CRC over magic + version + dpi + lod (same field order / algorithm as before for KV compat)
static uint32_t settings_payload_crc(const SettingsRecord &rec) {
    const uint8_t magic_le[4] = {
        (uint8_t)(rec.magic),
        (uint8_t)(rec.magic >> 8),
        (uint8_t)(rec.magic >> 16),
        (uint8_t)(rec.magic >> 24),
    };
    const uint8_t fields[4] = {
        (uint8_t)(rec.version),
        (uint8_t)(rec.version >> 8),
        rec.dpi,
        rec.lod,
    };
    uint32_t crc = crc32_update(0, magic_le, sizeof(magic_le));
    return crc32_update(crc, fields, sizeof(fields));
}

static void spi_begin();
static void spi_end();
static void spi_write(uint8_t addr, uint8_t data);
static uint8_t spi_read(uint8_t addr);
static MotionBurstData spi_read_motion_burst(bool do_update_wheel);
static void pmw3360_boot();
static void pmw3360_config();
static void srom_upload();
static void update_wheel();
static void update_buttons();
static void setup_buttons();
static bool sensor_srom_observation_ok();
static void enter_limp_mode(const char *reason);
static void try_sensor_recovery();
static void settings_load();
static void settings_mark_dirty();
static void settings_flush_if_due();
static bool settings_save();
static void check_config_inputs();
static int16_t sat_add_i16(int16_t a, int16_t b);
static int8_t sat_add_i8(int8_t a, int8_t b);
static uint8_t pack_hid_buttons(uint8_t phys);

// --- Sensor state ---
static bool mouse_inited = false;
static bool sensor_degraded = false; // no real SROM, but tracking enabled
static bool sensor_limp = false;
static uint8_t sensor_fail_streak = 0;
static uint32_t last_sensor_recovery_ms = 0;

// --- Settings ---
static uint8_t dpi = DPI_DEFAULT;
static uint8_t lod = LOD_DEFAULT;
static bool settings_dirty = false;
static uint32_t settings_dirty_ms = 0;

// --- Buttons / wheel ---
static uint32_t pins_state = 0;
static uint8_t buttons = 0;
static uint8_t buttons_latch[PHYS_COUNT] = {0};

static volatile uint32_t *const gpio_oe_set = (uint32_t *)0xd0000024;
static volatile uint32_t *const gpio_oe_clr = (uint32_t *)0xd0000028;
static volatile uint32_t *const gpio_in = (uint32_t *)0xd0000004;

static uint8_t wheel_state_a = 0;
static uint8_t wheel_state_b = 0;
static uint8_t wheel_state_output = 0;
static int8_t wheel_progress = 0;

// --- USB pending report ---
static int16_t pending_x = 0;
static int16_t pending_y = 0;
static int8_t pending_wheel = 0;
static uint8_t pending_buttons = 0;
static uint32_t usb_fail_count = 0;
static uint32_t usb_recover_count = 0;
static bool usb_had_pending_fail = false;

static void setup_buttons() {
    pinMode(BUTTONS_OFF, INPUT);
    pinMode(BUTTONS_ON, INPUT);
    pinMode(BUTTON_M1, INPUT_PULLUP);
    pinMode(BUTTON_M2, INPUT_PULLUP);
    pinMode(BUTTON_M3, INPUT_PULLUP);
    pinMode(BUTTON_M4, INPUT_PULLUP);
    pinMode(BUTTON_M5, INPUT_PULLUP);
    pinMode(BUTTON_DPI, INPUT_PULLUP);

    pinMode(ENCODER_A, INPUT_PULLUP);
    pinMode(ENCODER_B, INPUT_PULLUP);
    pinMode(ENCODER_COM, OUTPUT);

    digitalWrite(ENCODER_COM, LOW);
}

void setup() {
    delay(BOOT_SERIAL_DELAY_MS);

    SPI.begin();
    pinMode(PIN_NCS, OUTPUT);

    digitalWrite(PIN_NCS, HIGH);
    delayMicroseconds(T_NCS_SCLK_US);
    digitalWrite(PIN_NCS, LOW);
    delayMicroseconds(T_NCS_SCLK_US);
    digitalWrite(PIN_NCS, HIGH);
    delayMicroseconds(T_NCS_SCLK_US);

    settings_load();
    pmw3360_boot();
    delay(10);
    pmw3360_config();
    setup_buttons();
}

static void update_buttons() {
    // Tri-state matrix: OE toggling is much faster than pinMode()
    *gpio_oe_clr = 1u << BUTTONS_OFF;
    *gpio_oe_set = 1u << BUTTONS_ON;

    digitalWrite(BUTTONS_ON, LOW);
    delayMicroseconds(1);
    uint32_t pins_on = ~*gpio_in;

    *gpio_oe_set = 1u << BUTTONS_OFF;
    *gpio_oe_clr = 1u << BUTTONS_ON;

    digitalWrite(BUTTONS_OFF, LOW);
    delayMicroseconds(1);
    uint32_t pins_off = ~*gpio_in;

    uint32_t pins_update = pins_on ^ pins_off;
    pins_state = (pins_state & (~pins_update)) | (pins_on & pins_update);

    uint8_t next_buttons = ((!!(pins_state & (1u << BUTTON_M1))) << PHYS_M1) |
                           ((!!(pins_state & (1u << BUTTON_M2))) << PHYS_M2) |
                           ((!!(pins_state & (1u << BUTTON_M3))) << PHYS_M3) |
                           ((!!(pins_state & (1u << BUTTON_DPI))) << PHYS_DPI) |
                           ((!!(pins_state & (1u << BUTTON_M4))) << PHYS_M4) |
                           ((!!(pins_state & (1u << BUTTON_M5))) << PHYS_M5);

    uint8_t ok_mask = 0;
    for (uint8_t i = 0; i < PHYS_COUNT; i++)
        if (buttons_latch[i] == 0)
            ok_mask |= PHYS_BIT(i);

    next_buttons = (next_buttons & ok_mask) | (buttons & ~ok_mask);

    for (uint8_t i = 0; i < PHYS_COUNT; i++) {
        if (((next_buttons ^ buttons) >> i) & 1)
            buttons_latch[i] = BUTTON_LATCH_LOOPS;
        else if (buttons_latch[i])
            buttons_latch[i] -= 1;
    }

    buttons = next_buttons;
}

static void update_wheel() {
    uint8_t wheel_new_a = digitalRead(ENCODER_A);
    uint8_t wheel_new_b = digitalRead(ENCODER_B);

    if (wheel_new_a != wheel_state_a || wheel_new_b != wheel_state_b) {
        if (wheel_new_a == wheel_new_b && wheel_state_output != wheel_new_a) {
            // scrolling up: B changes first; scrolling down: A changes first
            if (wheel_new_b == wheel_state_b)
                wheel_progress += 1;
            // skip illegal 00<->11 jumps
            else if (wheel_new_a == wheel_state_a)
                wheel_progress -= 1;

            wheel_state_output = wheel_new_a;
        }

        wheel_state_a = wheel_new_a;
        wheel_state_b = wheel_new_b;
    }
}

static uint8_t pack_hid_buttons(uint8_t phys) {
    uint8_t hid = 0;
    bool middle_shared = false;

    for (uint8_t i = 0; i < PHYS_COUNT; i++) {
        if (!(phys & PHYS_BIT(i)))
            continue;

        uint8_t map = BUTTON_MAP[i];
        if (map == HID_NONE)
            continue;
        if (map == HID_MIDDLE_SHARED) {
            middle_shared = true;
            continue;
        }
        if (map <= HID_FORWARD)
            hid |= (1u << map);
    }

    if (middle_shared)
        hid |= (1u << HID_MIDDLE);

    return hid;
}

static uint8_t dpi_step_up(uint8_t value) {
    if (value < 16)
        return 1;
    if (value < 32)
        return 2;
    if (value < 64)
        return 4;
    return 8;
}

static uint8_t dpi_step_down(uint8_t value) {
    if (value <= 16)
        return 1;
    if (value <= 32)
        return 2;
    if (value <= 64)
        return 4;
    return 8;
}

static void check_config_inputs() {
    const bool dpi_chord = (buttons & CHORD_DPI) == CHORD_DPI;
    const bool lod_chord = (buttons & CHORD_LOD) == CHORD_LOD;

    if (dpi_chord && !lod_chord) {
        uint8_t olddpi = dpi;
        if (wheel_progress < 0) {
            uint8_t step = dpi_step_up(dpi);
            if (dpi <= DPI_MAX - step)
                dpi = (uint8_t)(dpi + step);
            else
                dpi = DPI_MAX;
        } else if (wheel_progress > 0) {
            uint8_t step = dpi_step_down(dpi);
            if (dpi >= DPI_MIN + step)
                dpi = (uint8_t)(dpi - step);
            else
                dpi = DPI_MIN;
        }

        if (olddpi != dpi) {
            spi_write(REG_CONFIG1, (uint8_t)(dpi - 1));
            printf("new DPI: %d\n", dpi * 100);
            settings_mark_dirty();
        }
        wheel_progress = 0;
    } else if (lod_chord && !dpi_chord) {
        uint8_t oldlod = lod;
        if (wheel_progress < 0) {
            if (lod < LOD_MAX)
                lod++;
        } else if (wheel_progress > 0) {
            if (lod > LOD_MIN)
                lod--;
        }

        if (oldlod != lod) {
            spi_write(REG_LIFT_CONFIG, lod);
            printf("new LOD: %d mm\n", lod);
            settings_mark_dirty();
        }
        wheel_progress = 0;
    }
}

static int16_t sat_add_i16(int16_t a, int16_t b) {
    int32_t sum = (int32_t)a + (int32_t)b;
    if (sum > 32767)
        return 32767;
    if (sum < -32767)
        return -32767;
    return (int16_t)sum;
}

static int8_t sat_add_i8(int8_t a, int8_t b) {
    int16_t sum = (int16_t)a + (int16_t)b;
    if (sum > 127)
        return 127;
    if (sum < -127)
        return -127;
    return (int8_t)sum;
}

static void settings_mark_dirty() {
    settings_dirty = true;
    settings_dirty_ms = millis();
}

static void settings_load() {
    SettingsRecord rec;
    size_t actual = 0;
    int res = kv_get(SETTINGS_KEY, &rec, sizeof(rec), &actual);
    if (res != MBED_SUCCESS || actual != sizeof(rec)) {
        printf("settings: using defaults (no saved record)\n");
        dpi = DPI_DEFAULT;
        lod = LOD_DEFAULT;
        return;
    }

    if (rec.magic != SETTINGS_MAGIC || rec.version != SETTINGS_VERSION ||
        rec.crc != settings_payload_crc(rec) || rec.dpi < DPI_MIN || rec.dpi > DPI_MAX ||
        rec.lod < LOD_MIN || rec.lod > LOD_MAX) {
        printf("settings: invalid record, using defaults\n");
        dpi = DPI_DEFAULT;
        lod = LOD_DEFAULT;
        return;
    }

    dpi = rec.dpi;
    lod = rec.lod;
    printf("settings: loaded DPI=%d LOD=%d\n", dpi * 100, lod);
}

static bool settings_save() {
    SettingsRecord rec;
    rec.magic = SETTINGS_MAGIC;
    rec.version = SETTINGS_VERSION;
    rec.dpi = dpi;
    rec.lod = lod;
    rec.crc = settings_payload_crc(rec);

    int res = kv_set(SETTINGS_KEY, &rec, sizeof(rec), 0);
    if (res != MBED_SUCCESS) {
        printf("settings: kv_set failed (%d)\n", res);
        return false;
    }
    printf("settings: saved DPI=%d LOD=%d\n", dpi * 100, lod);
    return true;
}

static void settings_flush_if_due() {
    if (!settings_dirty)
        return;
    if ((millis() - settings_dirty_ms) < SETTINGS_FLUSH_MS)
        return;

    if (settings_save())
        settings_dirty = false;
    else
        settings_dirty_ms = millis(); // retry later
}

static bool sensor_srom_observation_ok() {
    spi_write(REG_OBSERVATION, 0x00);
    delay(10);
    uint8_t obs = spi_read(REG_OBSERVATION);
    printf("observation: 0x%02X\n", obs);
    return (obs & OBS_SROM_RUNNING) != 0;
}

static void enter_limp_mode(const char *reason) {
    if (!sensor_limp)
        printf("sensor limp: %s\n", reason);
    sensor_limp = true;
    mouse_inited = false;
}

static void try_sensor_recovery() {
    uint32_t now = millis();
    if ((now - last_sensor_recovery_ms) < SENSOR_RECOVERY_COOLDOWN_MS)
        return;
    if (buttons != 0 || wheel_progress != 0 || pending_x || pending_y || pending_wheel)
        return;

    last_sensor_recovery_ms = now;
    printf("sensor: attempting recovery\n");
    pmw3360_boot();
    delay(10);
    if (mouse_inited || sensor_degraded) {
        pmw3360_config();
        sensor_limp = false;
        sensor_fail_streak = 0;
        printf("sensor: recovery ok\n");
    }
}

void loop() {
    update_wheel();
    delayMicroseconds(WHEEL_POLL_US);
    update_wheel();

    int16_t x = 0;
    int16_t y = 0;

    MotionBurstData data = spi_read_motion_burst(true);

    // Invalid SPI responses (all 0xFF) indicate a bus/sensor fault; zero SQUAL alone is
    // normal when lifted
    bool burst_bus_fault = (data.motion == 0xFF && data.observation == 0xFF && data.squal == 0xFF);
    if (burst_bus_fault) {
        if (sensor_fail_streak < 255)
            sensor_fail_streak++;
        if (sensor_fail_streak >= SENSOR_FAIL_STREAK_LIMIT)
            enter_limp_mode("invalid motion burst");
    } else if (sensor_fail_streak) {
        sensor_fail_streak--;
    }

    if ((mouse_inited || sensor_degraded) && !sensor_limp && data.motion) {
        x = data.x;
        y = data.y;
    }

    update_wheel();
    update_buttons();
    check_config_inputs();
    settings_flush_if_due();

    if (sensor_limp)
        try_sensor_recovery();

    int8_t wheel = wheel_progress;
    wheel_progress = 0;

    pending_x = sat_add_i16(pending_x, x);
    pending_y = sat_add_i16(pending_y, y);
    pending_wheel = sat_add_i8(pending_wheel, wheel);
    pending_buttons = pack_hid_buttons(buttons);

    // mouse.update blocks until the ~1 ms HID interval; return false means drop/coalesce
    bool ok = mouse.update(pending_x, pending_y, pending_buttons, pending_wheel);
    if (ok) {
        if (usb_had_pending_fail) {
            usb_recover_count++;
            usb_had_pending_fail = false;
            printf("usb: recovered (fails=%lu recovers=%lu)\n", (unsigned long)usb_fail_count,
                   (unsigned long)usb_recover_count);
        }
        pending_x = 0;
        pending_y = 0;
        pending_wheel = 0;
    } else {
        usb_fail_count++;
        usb_had_pending_fail = true;
        // keep pending_* for next loop; newest buttons already stored
    }
}

static void pmw3360_boot() {
    mouse_inited = false;
    sensor_degraded = false;

    spi_write(REG_POWER_UP_RESET, 0x5A);
    delay(50);

    spi_read(REG_MOTION);
    spi_read(REG_DELTA_X_L);
    spi_read(REG_DELTA_X_H);
    spi_read(REG_DELTA_Y_L);
    spi_read(REG_DELTA_Y_H);

    uint8_t product_id = spi_read(REG_PRODUCT_ID);
    uint8_t inverse_product_id = spi_read(REG_INVERSE_PRODUCT_ID);
    printf("product id: %d (inverse: %d)\n", product_id, inverse_product_id);
    if (product_id != PMW3360_PRODUCT_ID || inverse_product_id != PMW3360_INVERSE_PRODUCT_ID) {
        printf("warning: unexpected PMW3360 product id; check SPI wiring\n");
        enter_limp_mode("bad product id");
        return;
    }

#ifdef HAVE_REAL_SROM
    srom_upload();
#else
    printf("warning: no real SROM header; tracking may glitch (spinouts/teleports)\n");
    printf("place srom_3360_0x05.h next to this sketch to enable SROM upload\n");
    sensor_degraded = true;
    mouse_inited = false;
    sensor_limp = false;
#endif
}

static void pmw3360_config() {
    spi_write(REG_CONFIG1, (uint8_t)(dpi - 1));
    spi_write(REG_LIFT_CONFIG, lod);
}

static void spi_begin() {
    SPI.beginTransaction(spisettings);
}

static void spi_end() {
    SPI.endTransaction();
}

static void spi_write(uint8_t addr, uint8_t data) {
    spi_begin();

    digitalWrite(PIN_NCS, LOW);
    delayMicroseconds(T_NCS_SCLK_US);

    SPI.transfer(addr | 0x80);
    SPI.transfer(data);

    delayMicroseconds(T_SCLK_NCS_WRITE_US);
    digitalWrite(PIN_NCS, HIGH);

    spi_end();

    delayMicroseconds(T_SWW_SWR_US);
}

static uint8_t spi_read(uint8_t addr) {
    spi_begin();

    digitalWrite(PIN_NCS, LOW);
    delayMicroseconds(T_NCS_SCLK_US);

    SPI.transfer(addr & 0x7F);

    delayMicroseconds(T_SRAD_US);

    uint8_t ret = SPI.transfer(0);

    delayMicroseconds(T_NCS_SCLK_US);
    digitalWrite(PIN_NCS, HIGH);

    spi_end();

    delayMicroseconds(T_SRW_SRR_US);

    return ret;
}

static MotionBurstData spi_read_motion_burst(bool do_update_wheel) {
    MotionBurstData ret = {0};

    // ~260us; sample wheel midway
    spi_write(REG_MOTION_BURST, 0x00);
    if (do_update_wheel)
        update_wheel();

    spi_begin();

    digitalWrite(PIN_NCS, LOW);
    delayMicroseconds(T_NCS_SCLK_US);

    SPI.transfer(REG_MOTION_BURST);

    delayMicroseconds(T_SRAD_MOTBR_US);

    ret.motion = SPI.transfer(0);
    ret.observation = SPI.transfer(0);
    ret.x = SPI.transfer(0);
    ret.x |= ((uint16_t)SPI.transfer(0)) << 8;
    ret.y = SPI.transfer(0);
    ret.y |= ((uint16_t)SPI.transfer(0)) << 8;
    ret.squal = SPI.transfer(0);
    digitalWrite(PIN_NCS, HIGH);
    delayMicroseconds(T_BEXIT_US);

    spi_end();

    return ret;
}
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

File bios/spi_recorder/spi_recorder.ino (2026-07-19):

// wiring example for ripping a PMW3360 SROM: https://i.imgur.com/EspAlvz.jpeg
// set the board to 240mhz or higher for best results (WARNING: higher than 240mhz only works with
// USB if you overvolt the MCU)
// this implements reading SPI mode 3. if you want a different mode, you need to edit these two
// lines:
//        uint32_t clockval = (1 << pin_clock);
//            if (newclock && !clockval && buff_i < buffsize)

#include <pico/stdlib.h>
#include <string.h>

#define buffsize 50000
#define pin_ncs 19
#define pin_dat1 17
#define pin_dat2 18
#define pin_clock 16
// Abort a stuck capture if NCS never rises (bad wiring)
#define CAPTURE_TIMEOUT_US 5000000UL

static uint8_t buff[buffsize];

void setup() {
    Serial.begin(2000000);

    pinMode(pin_ncs, INPUT);
    pinMode(pin_dat1, INPUT);
    pinMode(pin_dat2, INPUT);
    pinMode(pin_clock, INPUT);

    delay(3000);
    Serial.println("booted");

    memset(buff, 0, buffsize);
}

void loop() {
    uint32_t pins = gpio_get_all();
    if (!(pins & (1 << pin_ncs))) {
        uint32_t buff_i = 0;
        uint32_t clockval = (1 << pin_clock);
        uint32_t start = micros();
        uint32_t n = 0;
        uint8_t bit = 0;
        bool timed_out = false;

        noInterrupts();
        do {
            n++;
            uint32_t newclock = pins & (1 << pin_clock);
            if (newclock && !clockval && buff_i < buffsize) {
                buff[buff_i] |= (!!(pins & (1 << pin_dat1))) << (7 - bit);
                bit += 1;
                if (bit == 8) {
                    bit = 0;
                    buff_i += 1;
                }
            }
            clockval = newclock;
            pins = gpio_get_all();
            if ((micros() - start) > CAPTURE_TIMEOUT_US) {
                timed_out = true;
                break;
            }
        } while (!(pins & (1 << pin_ncs)));
        interrupts();

        uint32_t end = micros();
        uint32_t elapsed = end - start;

        if (timed_out) {
            Serial.println("capture timed out waiting for NCS high; check wiring");
        } else if (buff_i > 100 && elapsed > 0) {
            Serial.printf("len: %d -- micros %d - khz %d - khz limit %d\n", buff_i, elapsed,
                          buff_i * 8 * 1000 / elapsed, n * 1000 / elapsed / 2);
            for (size_t i = 0; i < buff_i; i++)
                Serial.printf("%02X, ", buff[i]);
            Serial.println("");
        }
        memset(buff, 0, buffsize);
    }
}

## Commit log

2026-07-17 Add SPI recorder implementation for PMW3360 SROM reading
2026-07-18 Enhance PMW3360 mouse firmware with improved SROM handling, button mapping, and hardware verification documentation. Added timeout for SPI capture to prevent hangs, updated Readme with runtime contro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
    [mouse_pic.kicad_pcb, mouse_pic.kicad_sch]
